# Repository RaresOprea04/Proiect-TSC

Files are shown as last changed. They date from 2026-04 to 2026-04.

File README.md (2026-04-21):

# InkTime - Open Source Smartwatch ⌚

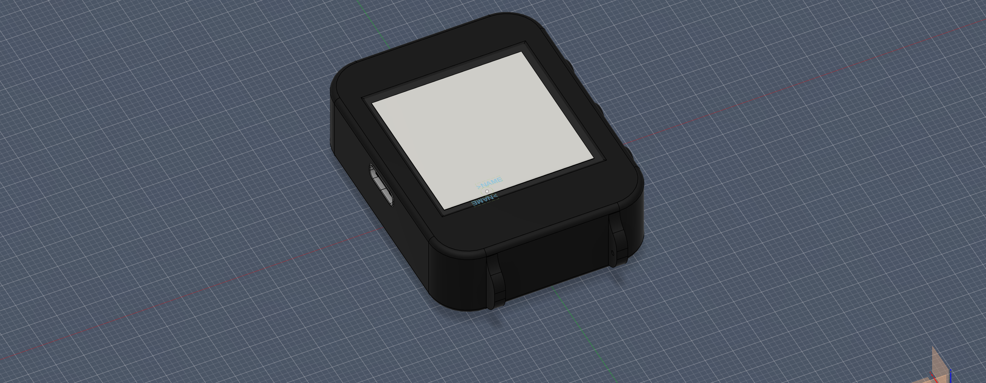
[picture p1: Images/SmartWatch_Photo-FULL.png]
InkTime Smartwatch


InkTime este un start-up care își propune să creeze un smartwatch accesibil și complet open-source. Acest repository conține fișierele FINALE, inclusiv design-ul hardware (schematic + PCB 2D/3D în Fusion 360), fișierele de fabricație și documentația aferentă, cât și ceas-ul în forma sa finală, asamblat.

## 1. Diagrama Bloc a Sistemului

Diagrama de mai jos ilustrează arhitectura hardware a ceasului InkTime, având în centru procesorul nRF52840, înconjurat de modulele de power management, senzori și interfața cu utilizatorul.

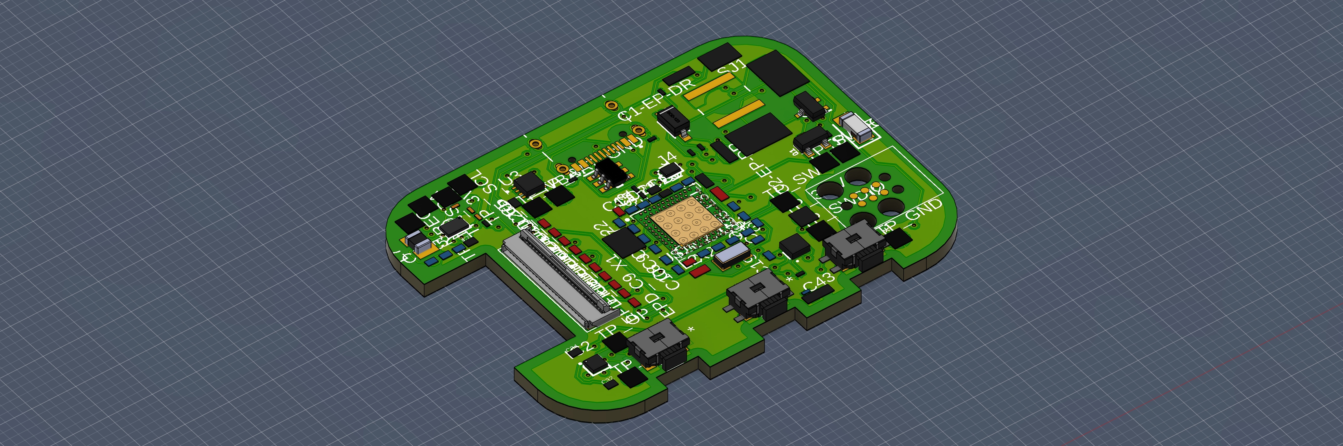
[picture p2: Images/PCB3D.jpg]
Diagrama Bloc
 

```mermaid
flowchart LR
    %% Stiluri
    classDef power fill:#f9d0c4,stroke:#333,stroke-width:2px;
    classDef mcu fill:#d4e6f1,stroke:#333,stroke-width:2px;
    classDef peri fill:#d5f5e3,stroke:#333,stroke-width:2px;

    %% Power Block
    subgraph Power Management
        USB[Conector USB-C]:::power -->|VBUS 5V| BQ[BQ25180\nCharger Li-Po]:::power
        BAT[(Baterie Li-Po)]:::power <-->|VBAT| BQ
        BQ -->|VSYS| REG[RT6160\nRegulator 3.3V]:::power
    end

    %% MCU Block
    MCU{nRF52840 SoC\nMCU + Antenă BLE}:::mcu

    %% Peripherals
    subgraph Senzori & UI
        ACC[BMA421\nAccelerometru]:::peri
        BTN[Butoane Tactile]:::peri
    end

    subgraph Output
        EPD[Ecran E-Paper]:::peri
    end

    Debug[Interfață SWD\nProgramare]:::peri

    %% Power Connections (Linii groase)
    REG == 3.3V === MCU
    REG == 3.3V === ACC
    REG == 3.3V === EPD

    %% Data Connections (Linii normale)
    MCU <-->|I2C| ACC
    MCU -->|SPI| EPD
    BTN -->|GPIO| MCU
    MCU <-->|SWDIO / SWCLK| Debug
```

## 2. Bill of Materials (BOM)

Toate componentele pasive (rezistențe, condensatoare) sunt în format SMD 0201 sau 0402, conform specificațiilor proiectului. Mai jos sunt componentele integrate principale (IC-urile):

| Componentă / Modul | Rol | JLCPCB Part Link | Datasheet |
| :--- | :--- | :--- | :--- |
| **nRF52840-QIAA** | MCU principal (Bluetooth LE) | [Caută JLC](https://jlcpcb.com/parts) | [Datasheet nRF52840](https://infocenter.nordicsemi.com/pdf/nRF52840_PS_v1.1.pdf) |
| **BQ25180YBGR** | PMIC / LiPo Battery Charger | [Caută JLC](https://jlcpcb.com/parts) | [Datasheet BQ25180](https://www.ti.com/lit/ds/symlink/bq25180.pdf) |
| **RT6160AWSC** | DC/DC Buck-Boost Converter (3.3V) | [Caută JLC](https://jlcpcb.com/parts) | [Datasheet RT6160](https://www.richtek.com/assets/product_file/RT6160A/DS6160A-01.pdf) |
| **MAX17048G+T10** | Fuel Gauge (Monitorizare Baterie) | [Caută JLC](https://jlcpcb.com/parts) | [Datasheet MAX17048](https://datasheets.maximintegrated.com/en/ds/MAX17048-MAX17049.pdf) |
| **BMA421** | Senzor IMU (Accelerometru) | [Caută JLC](https://jlcpcb.com/parts) | [Datasheet BMA421](https://www.bosch-sensortec.com/media/boschsensortec/downloads/datasheets/bst-bma421-fl000.pdf) |
| **DRV2605YZFR** | Haptic Motor Driver | [Caută JLC](https://jlcpcb.com/parts) | [Datasheet DRV2605](https://www.ti.com/lit/ds/symlink/drv2605.pdf) |
| **E-Paper Display** | Conector Display FPC 24-pin | - | - |

---

## 3. Funcționalitate Hardware și Arhitectură

Sistemul este construit în jurul microcontroller-ului **Nordic nRF52840**, ales pentru eficiența energetică ridicată și capabilitățile native Bluetooth Low Energy (BLE). 

### Alimentare (Power Management)
* **Încărcare:** Sistemul folosește un încărcător liniar **BQ25180** compatibil cu baterii LiPo, alimentat prin mufa USB-C (5V). 
* **Regulare:** Deoarece bateria variază între 3.0V și 4.2V, folosim un convertor DC/DC Buck-Boost **RT6160** pentru a menține o tensiune stabilă de 3.3V necesară componentelor logice și display-ului.
* **Monitorizare:** Modulul **MAX17048** comunică prin I2C pentru a oferi SoC-ului informații exacte despre procentajul bateriei (State of Charge).

### Senzori și Interacțiune
* **Membru senzorial:** Un IMU **BMA421** comunică prin I2C cu microcontroller-ul. Folosește pini de interupt pentru a trezi procesorul (Wake-on-Motion), economisind astfel energie (ex: se aprinde display-ul doar când ridici mâna).
* **Display E-Paper:** Este controlat printr-o magistrală SPI (MISO, MOSI, SCK, CS) la care se adaugă semnalele de control specifice ecranelor cu cerneală electronică (BUSY, DC, RESET). Avantajul suprem este că ecranul reține imaginea fără a consuma energie (0mA consum static).
* **Feedback Haptic:** Un driver dedicat **DRV2605** este conectat pe magistrala I2C și controlează un motor de vibrații (shaker) pentru notificări.
* **Input Utilizator:** 3 butoane fizice cu rezistențe de pull-up hardware/software pentru navigarea în meniu.

### Estimări de consum energetic
* **Sleep Mode (System OFF):** ~1.5uA (nRF52840) + curenții de stand-by ai senzorilor = **< 5uA total**.
* **Display Refresh:** ~8mA timp de 1-2 secunde (doar la actualizarea orei).
* **BLE Tx/Rx Active:** ~5.3mA pe vârfuri scurte (câteva milisecunde).
Sistemul este extrem de eficient, asigurând o durată de viață a bateriei de câteva săptămâni, în funcție de frecvența refresh-urilor e-paper.

---

## 4. Maparea Pinilor nRF52840 (Pinout)

| Pin nRF52840 | Nume Semnal | Destinație | Rol / Explicație |
| :--- | :--- | :--- | :--- |
| `P0.06` | I2C_SDA | BMA421, BQ25180, MAX17048, DRV2605 | Linia de date pentru magistrala I2C comună. |
| `P0.07` | I2C_SCL | BMA421, BQ25180, MAX17048, DRV2605 | Linia de clock pentru magistrala I2C comună. |
| `P0.03` | SPI_MOSI | E-Paper Connector | Trimite comenzi și date de imagine către display. |
| `P0.02` | SPI_SCK | E-Paper Connector | Semnalul de clock pentru interfața SPI a display-ului. |
| `P0.05` | EPD_CS | E-Paper Connector | Chip Select (active low) pentru display-ul E-paper. |
| `P0.15` | EPD_DC | E-Paper Connector | Data/Command - indică dacă payload-ul trimis prin SPI este o comandă sau date de pixel. |
| `P0.17` | EPD_BUSY | E-Paper Connector | Citește starea de busy a display-ului pentru a ști când s-a terminat refresh-ul. |
| `P0.16` | EPD_RST | E-Paper Connector | Pinul de hardware reset pentru ecranul E-paper. |
| `P0.08` | IMU_INT1 | BMA421 | Wake-up interrupt (ex: trezirea sistemului la ridicarea mâinii). |
| `P1.04` | SW_UP | Buton Sus | Input navigație (activ low, folosind pull-up intern). |
| `P1.05` | SW_ENT | Buton Enter | Input navigație (activ low, folosind pull-up intern). |
| `P1.06` | SW_DN | Buton Jos | Input navigație (activ low, folosind pull-up intern). |

---

## 5. Design Log & Constrângeri pentru Review

### Imagini PCB și Asamblare 3D
*Aici puteți vedea design-ul plăcii de circuit și integrarea acesteia în carcasa printată.*

**Vedere PCB (Top & Bottom):**
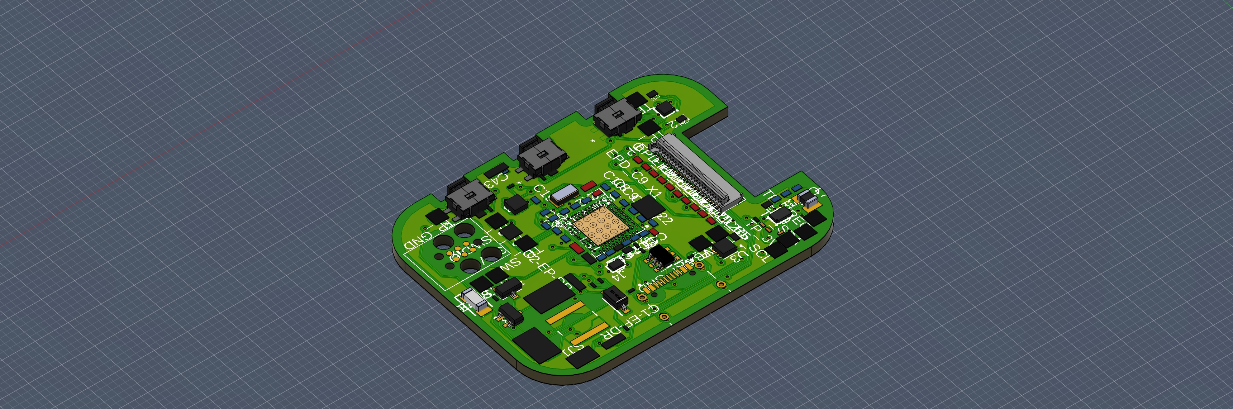
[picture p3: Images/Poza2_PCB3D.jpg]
PCB View 1

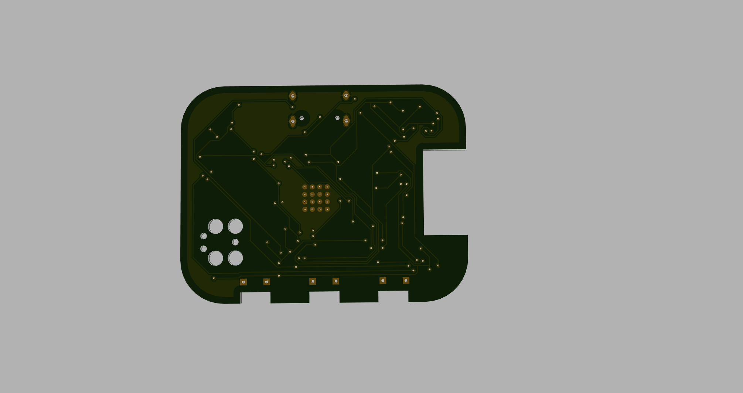
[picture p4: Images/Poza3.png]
PCB View 2


**Integrare în Carcasă (Asamblare internă):**
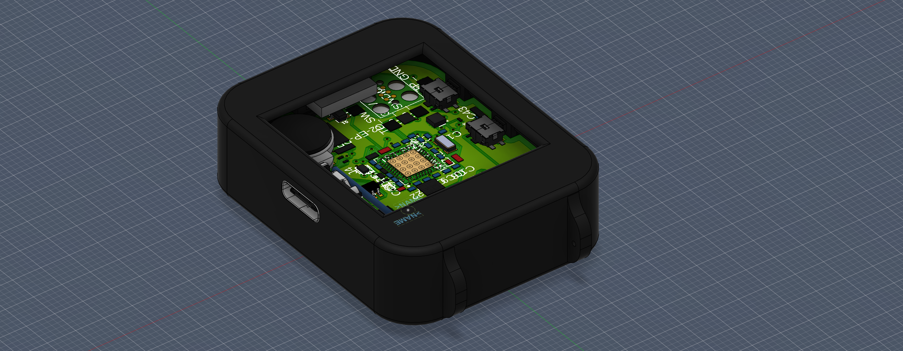
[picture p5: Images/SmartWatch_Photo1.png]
Asamblare 1

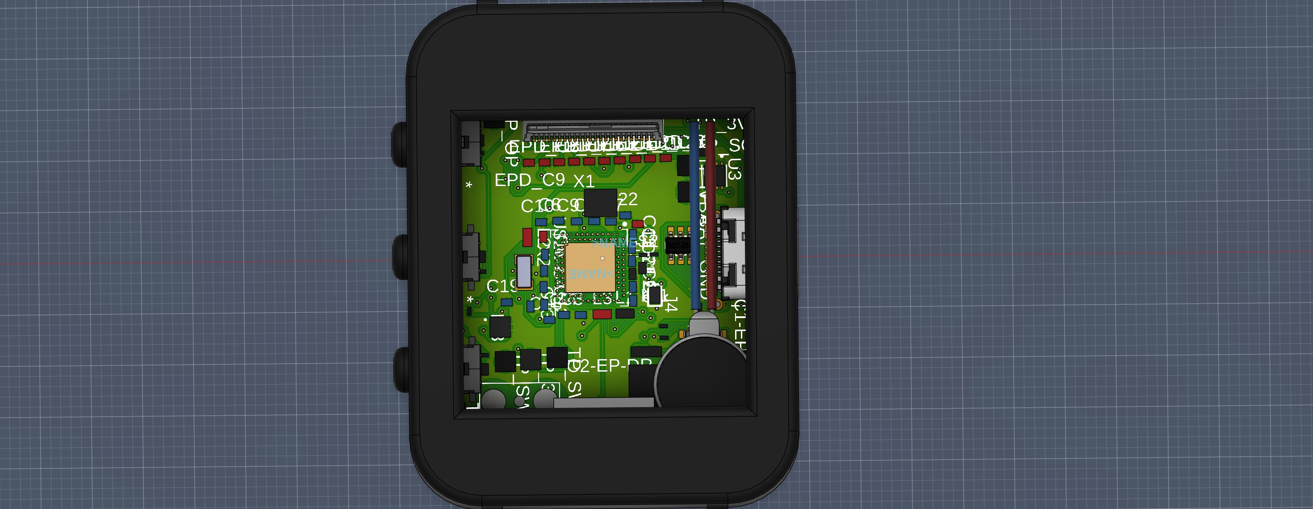
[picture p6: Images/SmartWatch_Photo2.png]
Asamblare 2

Asamblare 3

### Jurnal de decizii (Design Log)
În timpul procesului de proiectare am respectat următoarele constrângeri și decizii de good-practice:
1. **Plane de Masă:** S-au implementat poligoane de GND atât pe layer-ul TOP cât și pe BOTTOM. S-a realizat Via Stitching abundent pentru a asigura un plan de referință solid, în special în apropierea modulului radio și a convertoarelor DC/DC.
2. **Zona Antenei:** Am respectat cu strictețe zona de clearance pentru antena integrată. S-a folosit un "Polygon Cutout" pe ambele straturi pentru a decupa cuprul complet de sub antenă, evitând astfel detunarea (detuning) acesteia și degradarea semnalului RF.
3. **Rutarea curentului:** Traseele de putere (VBUS, 3V3, VBAT) au fost rutate la o grosime optimizată de 0.3mm (unde spațiul a permis) pentru a minimiza căderea de tensiune, iar condensatoarele de decuplare (100nF) au fost amplasate strict, cât mai aproape de pinii de VDD ai integratelor.
4. **Acceptare Erori DRC:** Erorile de clearance și dimension rezultate din depășirea marginii plăcii de către componentele mecanice (mufa USB-C și butoanele fizice) au fost acceptate asumat, deoarece amplasarea lor este impusă de cotele carcasei exterioare.

---

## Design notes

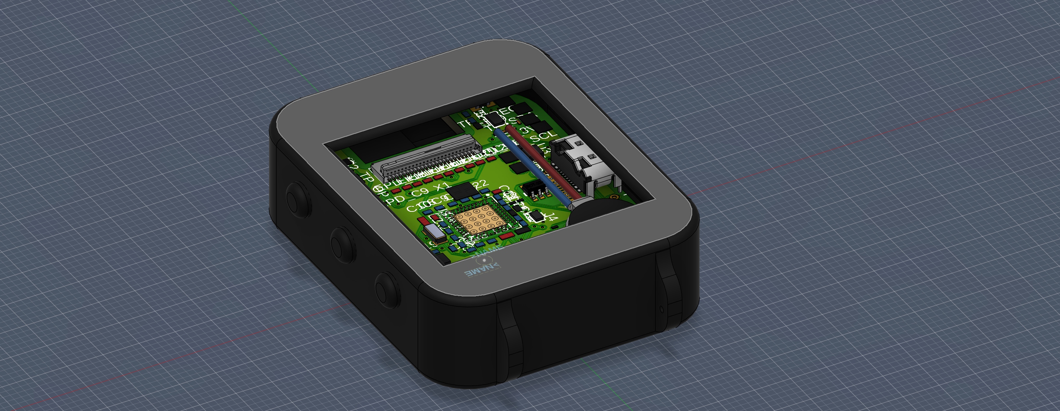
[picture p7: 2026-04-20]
Images/SmartWatch_Photo3.png

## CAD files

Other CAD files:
Mechanical/SmartWatch Final.f3z

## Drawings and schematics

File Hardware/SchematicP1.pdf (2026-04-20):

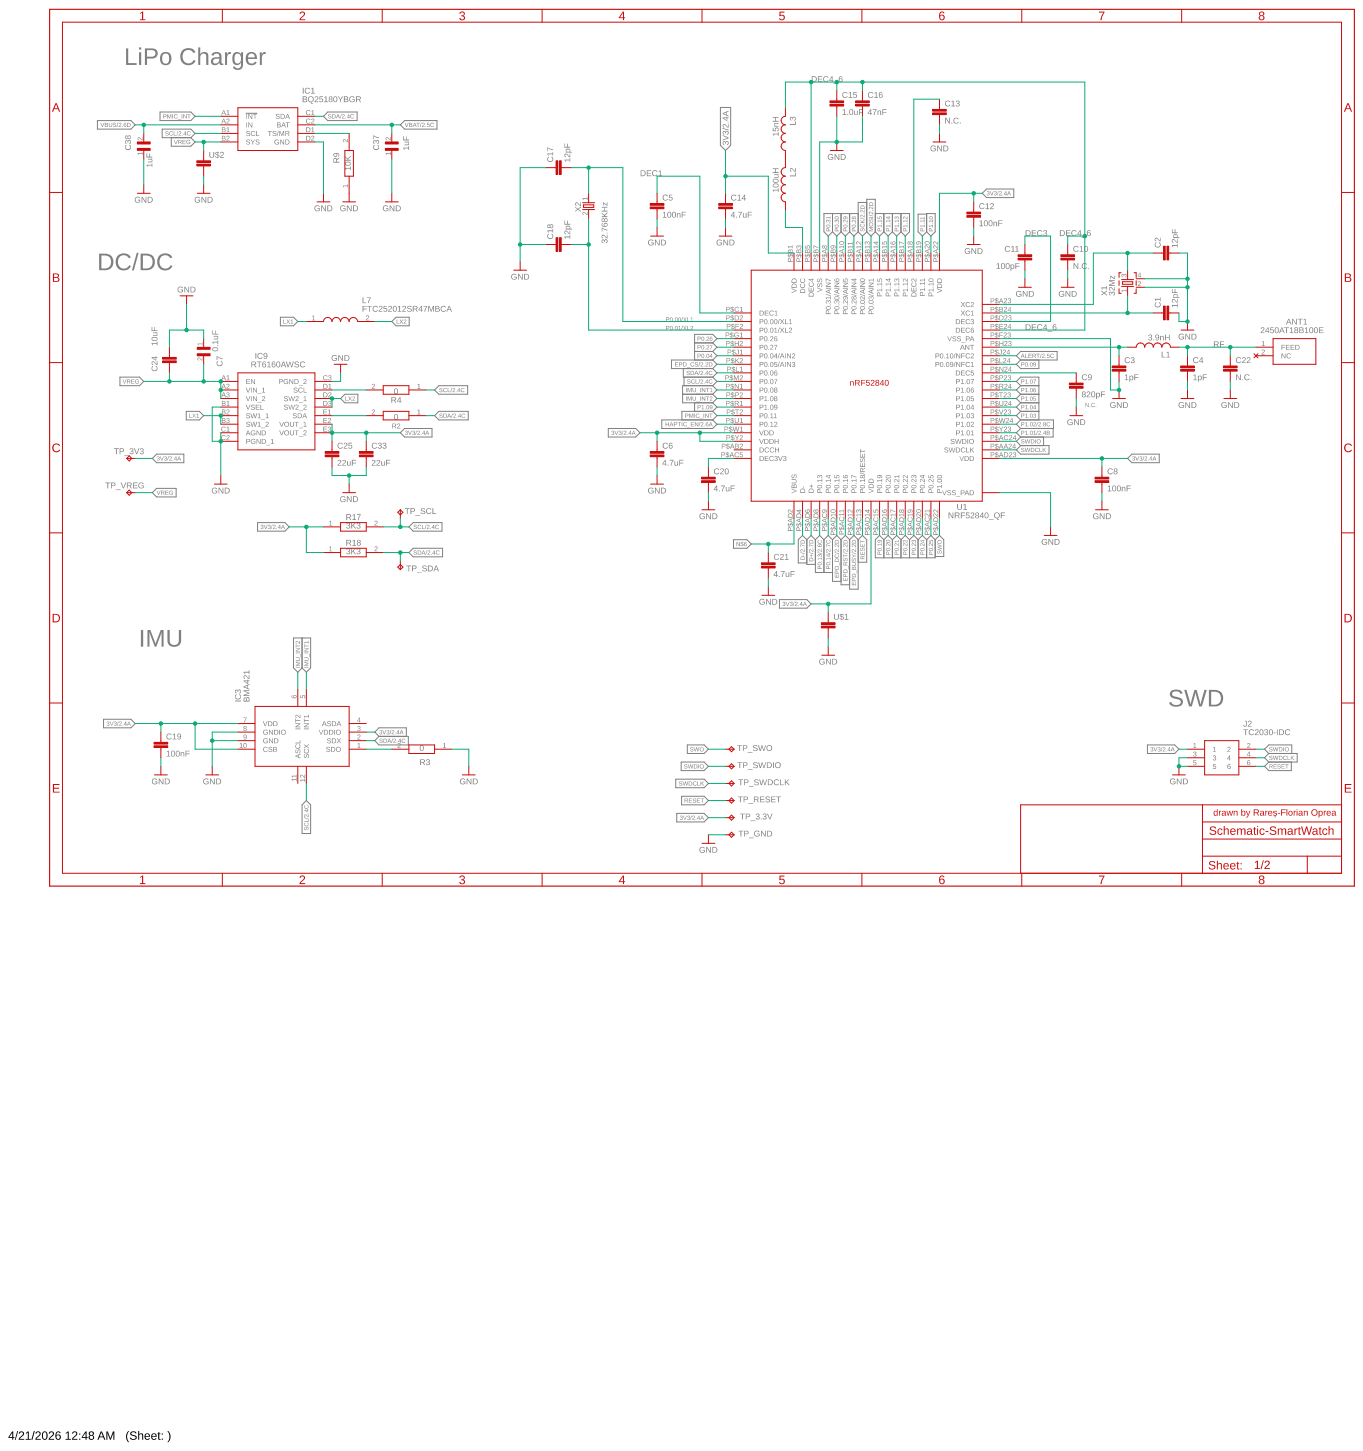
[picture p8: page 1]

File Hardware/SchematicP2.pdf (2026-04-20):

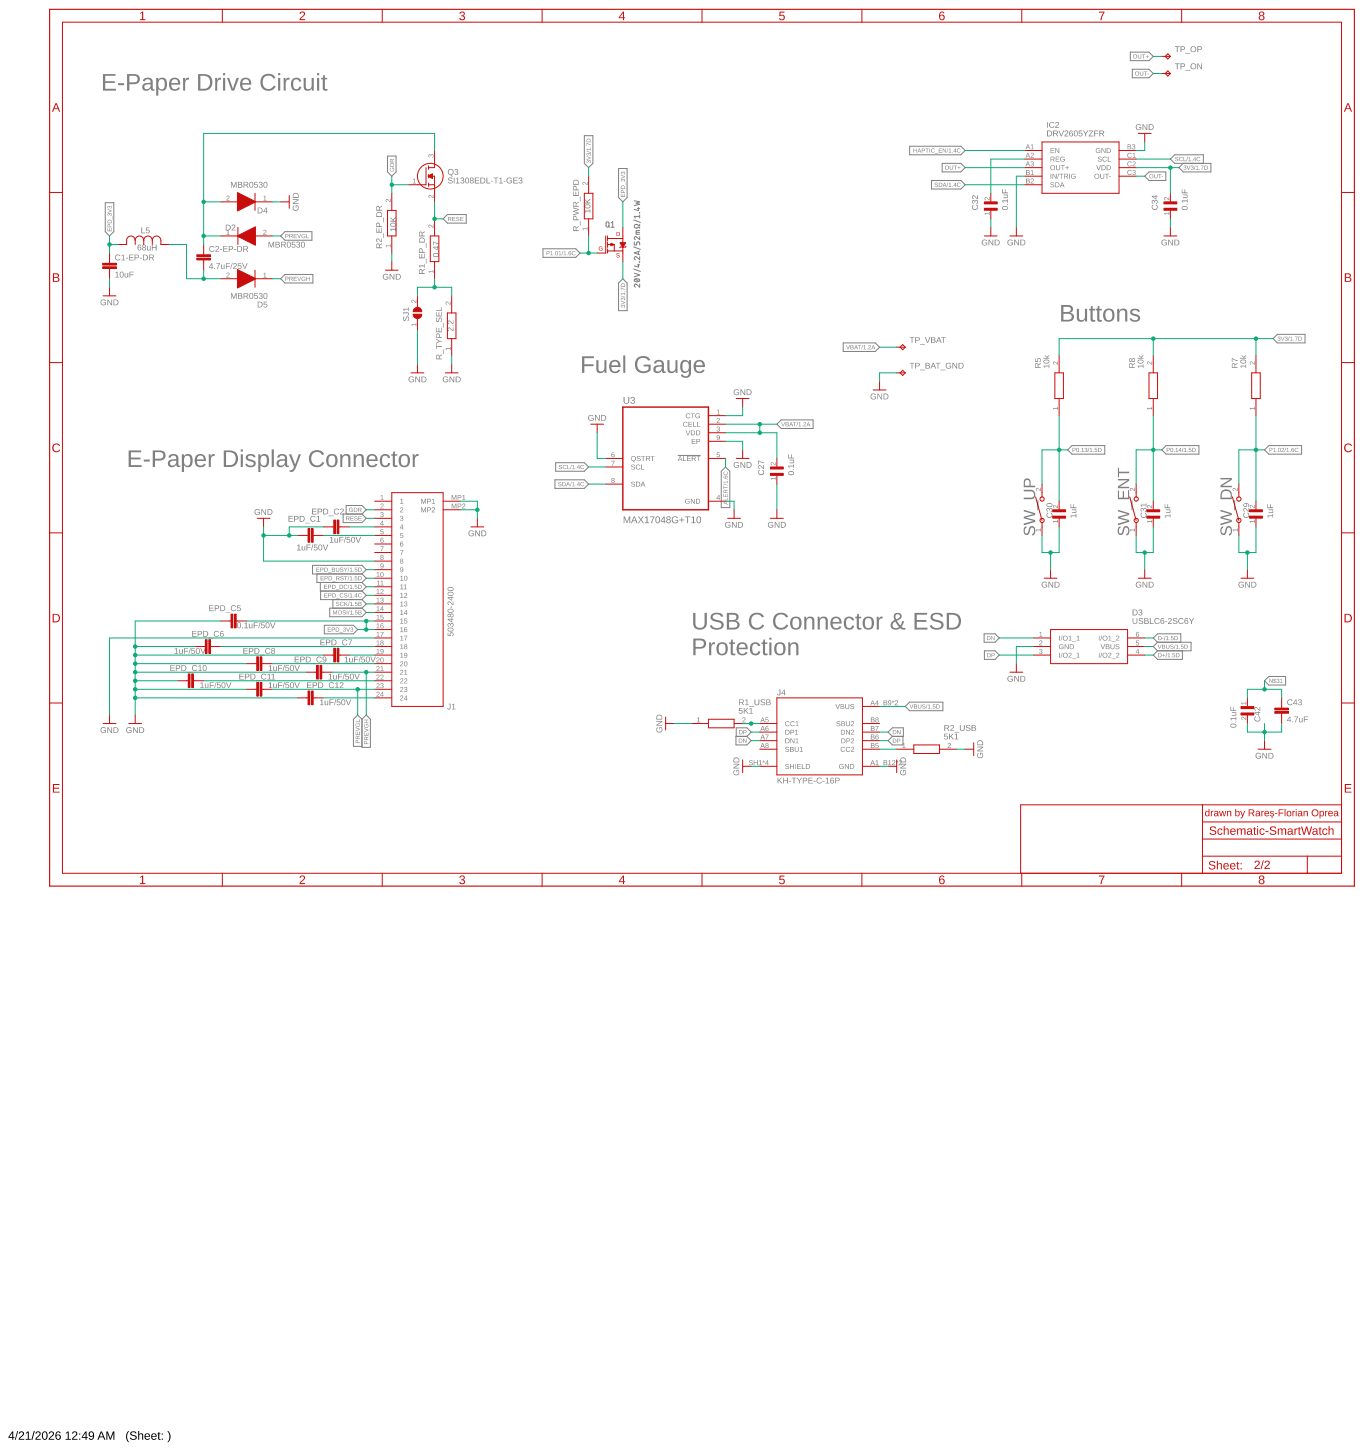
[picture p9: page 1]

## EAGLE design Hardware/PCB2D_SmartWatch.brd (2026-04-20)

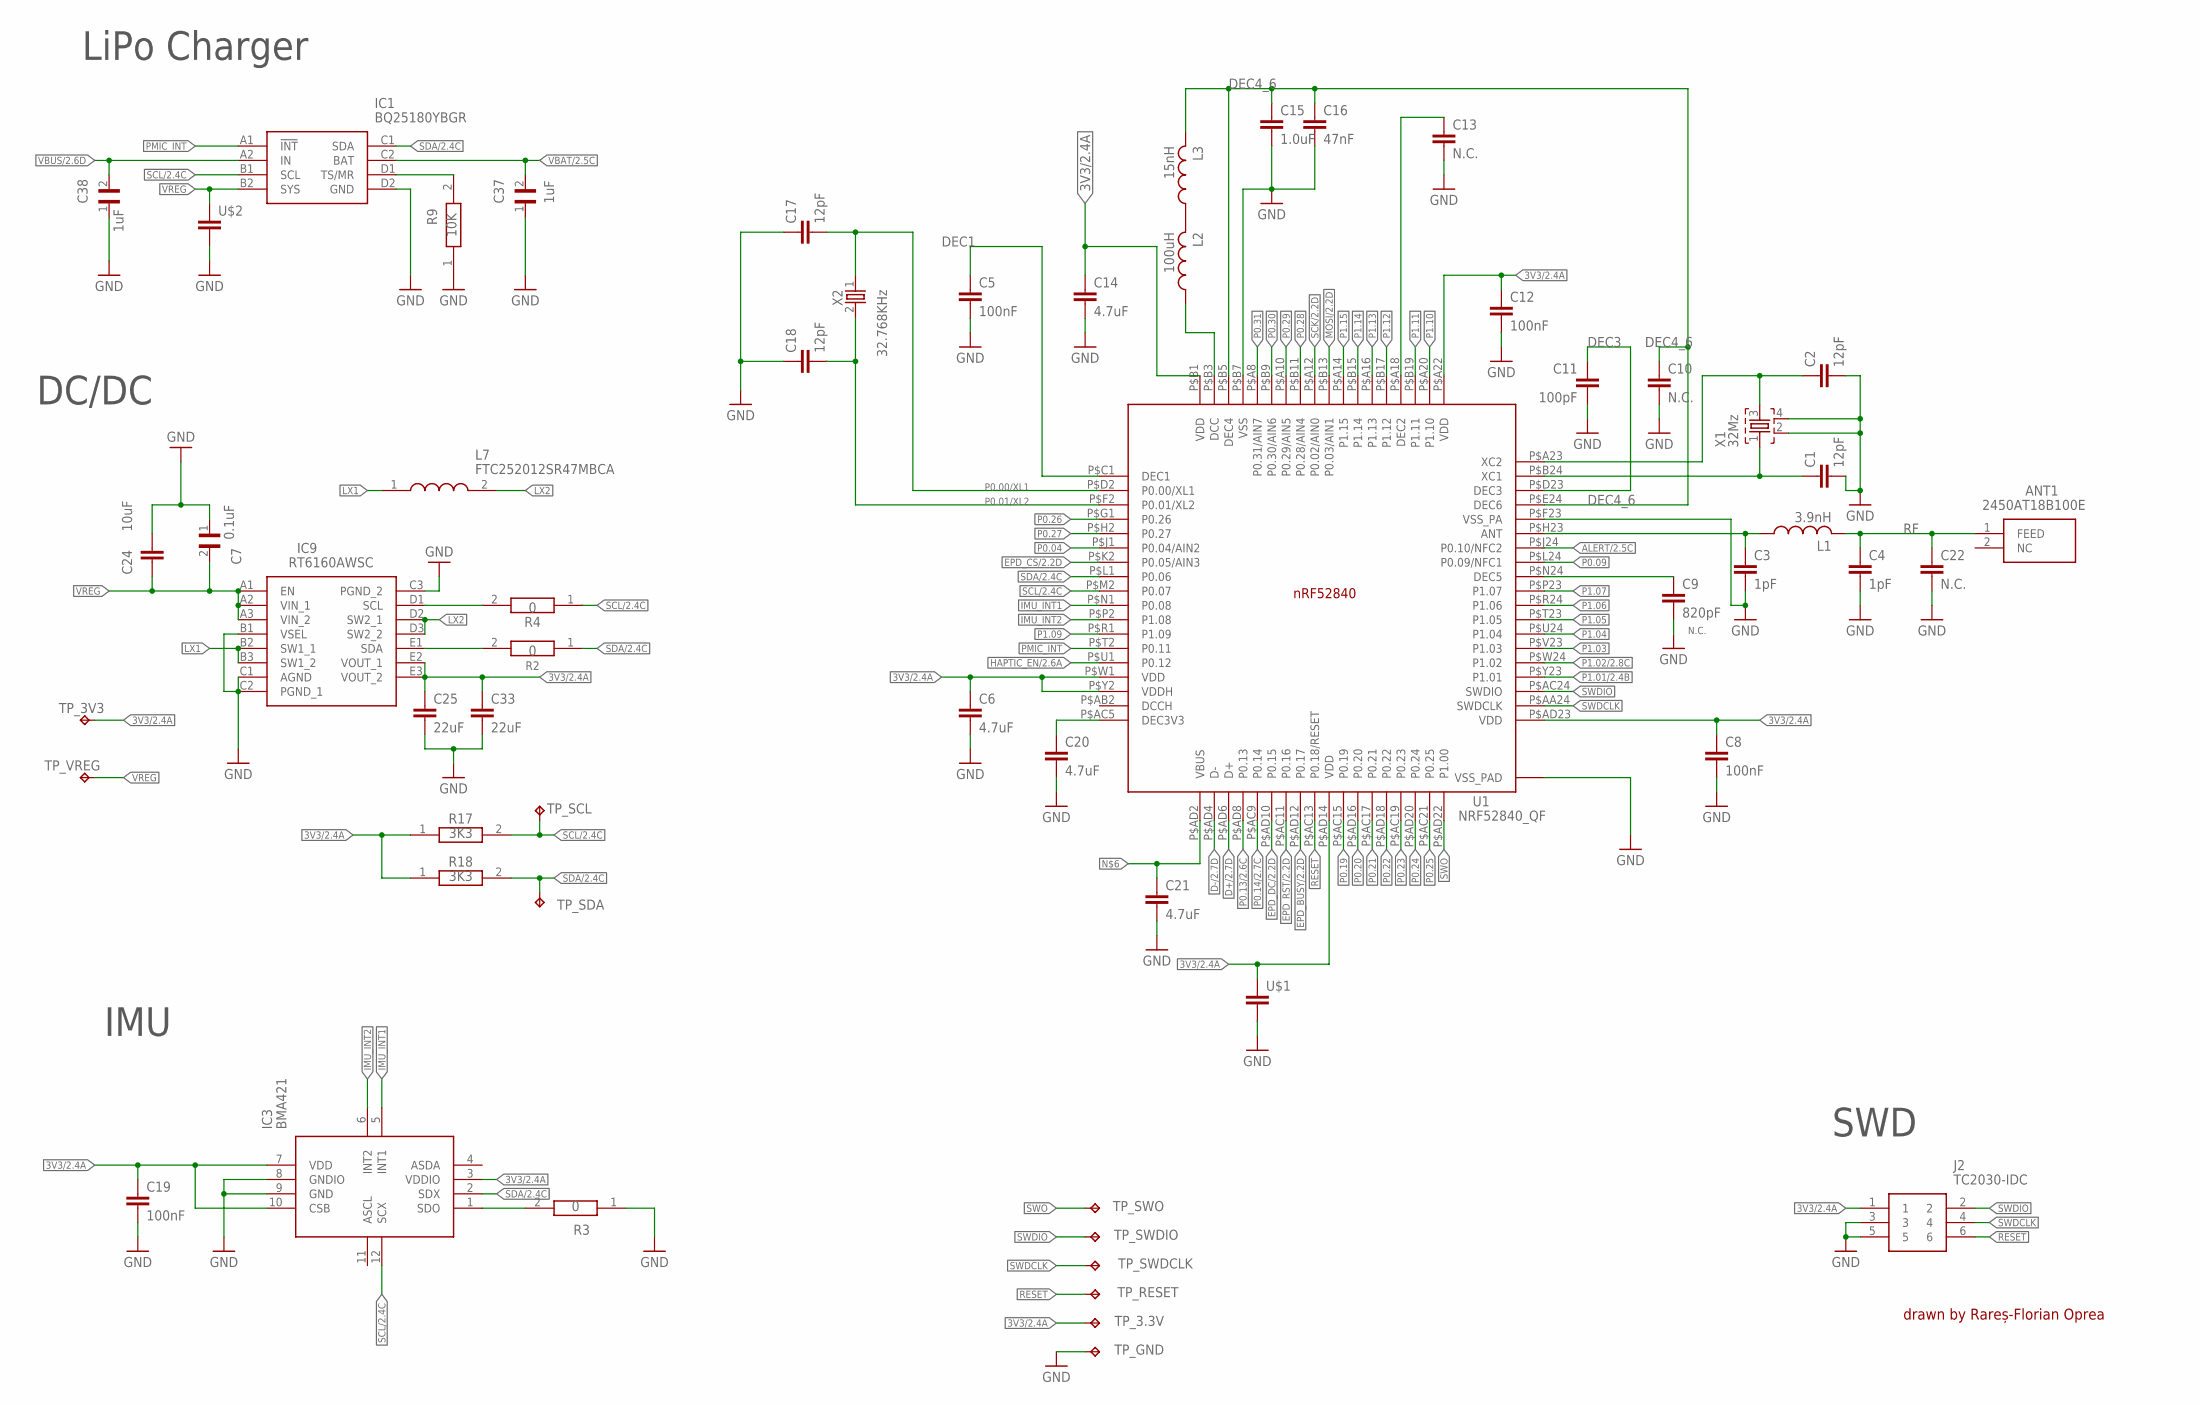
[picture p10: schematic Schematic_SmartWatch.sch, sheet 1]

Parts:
ANT1: 2450AT18B100E; 2450AT18B100E_ANTC3216X140N
C1, C2, C17, C18: 12pF; NORDIC_NRF_3_RESC0201_L
C3, C4: 1pF; NORDIC_NRF_3_RESC0201_L
C5, C8, C12, C19: 100nF; NORDIC_NRF_3_RESC0201_L
C6, C14, C20, C21: 4.7uF; NORDIC_NRF_3_RESC0201_L
C7: 0.1uF; GRM011R60J152KE01L_2_CAPC0201X13N
C9: 820pF; NORDIC_NRF_3_RESC0201_L
C10, C13, C22: N.C.; NORDIC_NRF_3_RESC0201_L
C11: 100pF; NORDIC_NRF_3_RESC0201_L
C15: 1.0uF; NORDIC_NRF_3_RESC0201_L
C16: 47nF; NORDIC_NRF_3_RESC0201_L
C24: 10uF; NORDIC_NRF_3_RESC0201_L
C25, C33: 22uF; NORDIC_NRF_3_RESC0201_L
C37: 1uF; GRM011R60J152KE01L_1_0201
C38: 1uF; GRM011R60J152KE01L_2_CAPC0201X13N
IC1: BQ25180YBGR; BQ25180YBGR_BGA8C40P2X4_100X155X50
IC3: BMA421; BMA423_BMA423
IC9: RT6160AWSC; RT6160AWSC_BGA15C40P3X5_140X230X60
J2: TC2030-IDC; TC2030-IDC_TC2030IDC
L1: 3.9nH; NORDIC_NRF_2_RESC0402_L
L2: 100uH; NORDIC_NRF_2_RESC0402_L
L3: 15nH; NORDIC_NRF_2_RESC0402_L
L7: FTC252012SR47MBCA; MLP2016SR47MT0S1_INDC2016X100N
R2, R4: 0; CPF0201D7K68C1_0201
R3: 0; ERA-1AEB3401C_0201
R9: 10K; ERA-1AEB3401C_0201
R17, R18: 3K3; CPF0201D7K68C1_0201
TP_3.3V, TP_3V3: HECTOR_WATCH_1_TPTP20R; HECTOR_WATCH_1_TP20R
TP_GND: HECTOR_WATCH_1_TPTP20R; HECTOR_WATCH_1_TP20R
TP_RESET: HECTOR_WATCH_1_TPTP20R; HECTOR_WATCH_1_TP20R
TP_SCL: HECTOR_WATCH_1_TPTP20R; HECTOR_WATCH_1_TP20R
TP_SDA: HECTOR_WATCH_1_TPTP20R; HECTOR_WATCH_1_TP20R
TP_SWDCLK: HECTOR_WATCH_1_TPTP20R; HECTOR_WATCH_1_TP20R
TP_SWDIO: HECTOR_WATCH_1_TPTP20R; HECTOR_WATCH_1_TP20R
TP_SWO: HECTOR_WATCH_1_TPTP20R; HECTOR_WATCH_1_TP20R
TP_VREG: HECTOR_WATCH_1_TPTP20R; HECTOR_WATCH_1_TP20R
U1: NRF52840_QF; NORDIC_NRF_4_AQFN50P700X700X85_HS-74N
U$1, U$2: NORDIC_NRF_3_CAPACITOR_0201_L; NORDIC_NRF_3_RESC0201_L
X1: 32Mz; NORDIC_NRF_BT-XTAL_2016_N
X2: 32.768KHz; NORDIC_NRF_1_XTAL_3215_N

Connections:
3V3/2.4A: C6.1, C8.1, C12.1, C14.1, C19.1, C25.1, C33.1, IC3.3 (VDDIO), IC3.7 (VDD), IC3.10 (CSB), IC9.E2 (VOUT_1), IC9.E3 (VOUT_2), J2.1, R17.1, R18.1, TP_3.3V.TP, TP_3V3.TP, U1.P$A22 (VDD), U1.P$AD14 (VDD), U1.P$AD23 (VDD), U1.P$B1 (VDD), U1.P$W1 (VDD), U1.P$Y2 (VDDH), U$1.1
ALERT/2.5C: U1.P$J24 (P0.10/NFC2)
D+/2.7D: U1.P$AD6 (D+)
D-/2.7D: U1.P$AD4 (D-)
DEC1: C5.1, U1.P$C1 (DEC1)
DEC3: C11.1, U1.P$D23 (DEC3)
DEC4_6: C10.1, C15.1, C16.1, L3.2, U1.P$B5 (DEC4), U1.P$E24 (DEC6)
EPD_BUSY/2.2D: U1.P$AD12 (P0.17)
EPD_CS/2.2D: U1.P$K2 (P0.05/AIN3)
EPD_DC/2.2D: U1.P$AD10 (P0.15)
EPD_RST/2.2D: U1.P$AC11 (P0.16)
GND: C1.2, C2.2, C3.2, C4.2, C5.2, C6.2, C7.1, C8.2, C10.2, C11.2, C12.2, C13.2, C14.2, C19.2, C20.2, C21.2, C22.2, C24.1, C37.1, C38.1, IC1.D2 (GND), IC3.8 (GNDIO), IC3.9 (GND), IC9.B1 (VSEL), IC9.C1 (AGND), IC9.C2 (PGND_1), J2.3, J2.5, R3.1, R9.1, TP_GND.TP, U1.P$74 (VSS_PAD), U1.P$75 (VSS_PAD), U1.P$76 (VSS_PAD), U1.P$77 (VSS_PAD), U1.P$78 (VSS_PAD), U1.P$79 (VSS_PAD), U1.P$80 (VSS_PAD), U1.P$81 (VSS_PAD), U1.P$82 (VSS_PAD), U1.P$83 (VSS_PAD), U1.P$84 (VSS_PAD), U1.P$85 (VSS_PAD), U1.P$86 (VSS_PAD), U1.P$87 (VSS_PAD), U1.P$88 (VSS_PAD), U1.P$89 (VSS_PAD), U1.P$90 (VSS_PAD), U1.P$F23 (VSS_PA), U$1.2, U$2.2, X1.2, X1.4; also elsewhere on the board
HAPTIC_EN/2.6A: U1.P$U1 (P0.12)
IMU_INT1: IC3.5 (INT1), U1.P$N1 (P0.08)
IMU_INT2: IC3.6 (INT2), U1.P$P2 (P1.08)
LX1: IC9.B2 (SW1_1), IC9.B3 (SW1_2), L7.1
LX2: IC9.D2 (SW2_1), IC9.D3 (SW2_2), L7.2
MOSI/2.2D: U1.P$B13 (P0.03/AIN1)
unnamed: L2.2, L3.1
unnamed: L2.1, U1.P$B3 (DCC)
unnamed: IC1.D1 (TS/MR), R9.2
unnamed: C15.2, C16.2, U1.P$B7 (VSS)
unnamed: C20.1, U1.P$AC5 (DEC3V3)
unnamed: C21.1, U1.P$AD2 (VBUS)
unnamed: C17.1, C18.1
unnamed: C3.1, L1.1, U1.P$H23 (ANT)
unnamed: C1.1, U1.P$B24 (XC1), X1.1
unnamed: C13.1, U1.P$A18 (DEC2)
unnamed: C9.1, U1.P$N24 (DEC5)
unnamed: C2.1, U1.P$A23 (XC2), X1.3
unnamed: IC3.1 (SDO), R3.2
unnamed: IC9.D1 (SCL), R4.2
unnamed: C25.2, C33.2
unnamed: IC9.E1 (SDA), R2.2
N.C.: C9.2
P0.00/XL1: C17.2, U1.P$D2 (P0.00/XL1), X2.1
P0.01/XL2: C18.2, U1.P$F2 (P0.01/XL2), X2.2
P0.04: U1.P$J1 (P0.04/AIN2)
P0.09: U1.P$L24 (P0.09/NFC1)
P0.13/2.6C: U1.P$AD8 (P0.13)
P0.14/2.7C: U1.P$AC9 (P0.14)
P0.19: U1.P$AC15 (P0.19)
P0.20: U1.P$AD16 (P0.20)
P0.21: U1.P$AC17 (P0.21)
P0.22: U1.P$AD18 (P0.22)
P0.23: U1.P$AC19 (P0.23)
P0.24: U1.P$AD20 (P0.24)
P0.25: U1.P$AC21 (P0.25)
P0.26: U1.P$G1 (P0.26)
P0.27: U1.P$H2 (P0.27)
P0.28: U1.P$B11 (P0.28/AIN4)
P0.29: U1.P$A10 (P0.29/AIN5)
P0.30: U1.P$B9 (P0.30/AIN6)
P0.31: U1.P$A8 (P0.31/AIN7)
P1.01/2.4B: U1.P$Y23 (P1.01)
P1.02/2.8C: U1.P$W24 (P1.02)
P1.03: U1.P$V23 (P1.03)
P1.04: U1.P$U24 (P1.04)
P1.05: U1.P$T23 (P1.05)
P1.06: U1.P$R24 (P1.06)
P1.07: U1.P$P23 (P1.07)
P1.09: U1.P$R1 (P1.09)
P1.10: U1.P$A20 (P1.10)
P1.11: U1.P$B19 (P1.11)
P1.12: U1.P$B17 (P1.12)
P1.13: U1.P$A16 (P1.13)
P1.14: U1.P$B15 (P1.14)
P1.15: U1.P$A14 (P1.15)
PMIC_INT: IC1.A1 (!INT), U1.P$T2 (P0.11)
RESET: J2.6, TP_RESET.TP, U1.P$AC13 (P0.18/RESET)
RF: ANT1.1 (FEED), C4.1, C22.1, L1.2
SCK/2.2D: U1.P$A12 (P0.02/AIN0)
SCL/2.4C: IC1.B1 (SCL), IC3.12 (SCX), R4.1, R17.2, TP_SCL.TP, U1.P$M2 (P0.07)
SDA/2.4C: IC1.C1 (SDA), IC3.2 (SDX), R2.1, R18.2, TP_SDA.TP, U1.P$L1 (P0.06)
SWDCLK: J2.4, TP_SWDCLK.TP, U1.P$AA24 (SWDCLK)
SWDIO: J2.2, TP_SWDIO.TP, U1.P$AC24 (SWDIO)
SWO: TP_SWO.TP, U1.P$AD22 (P1.00)
VBAT/2.5C: C37.2, IC1.C2 (BAT)
VBUS/2.6D: C38.2, IC1.A2 (IN)
VREG: C7.2, C24.2, IC1.B2 (SYS), IC9.A1 (EN), IC9.A2 (VIN_1), IC9.A3 (VIN_2), TP_VREG.TP, U$2.1

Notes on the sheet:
LiPo Charger
IMU
DC/DC
SWD
drawn by Rareș-Florian Oprea

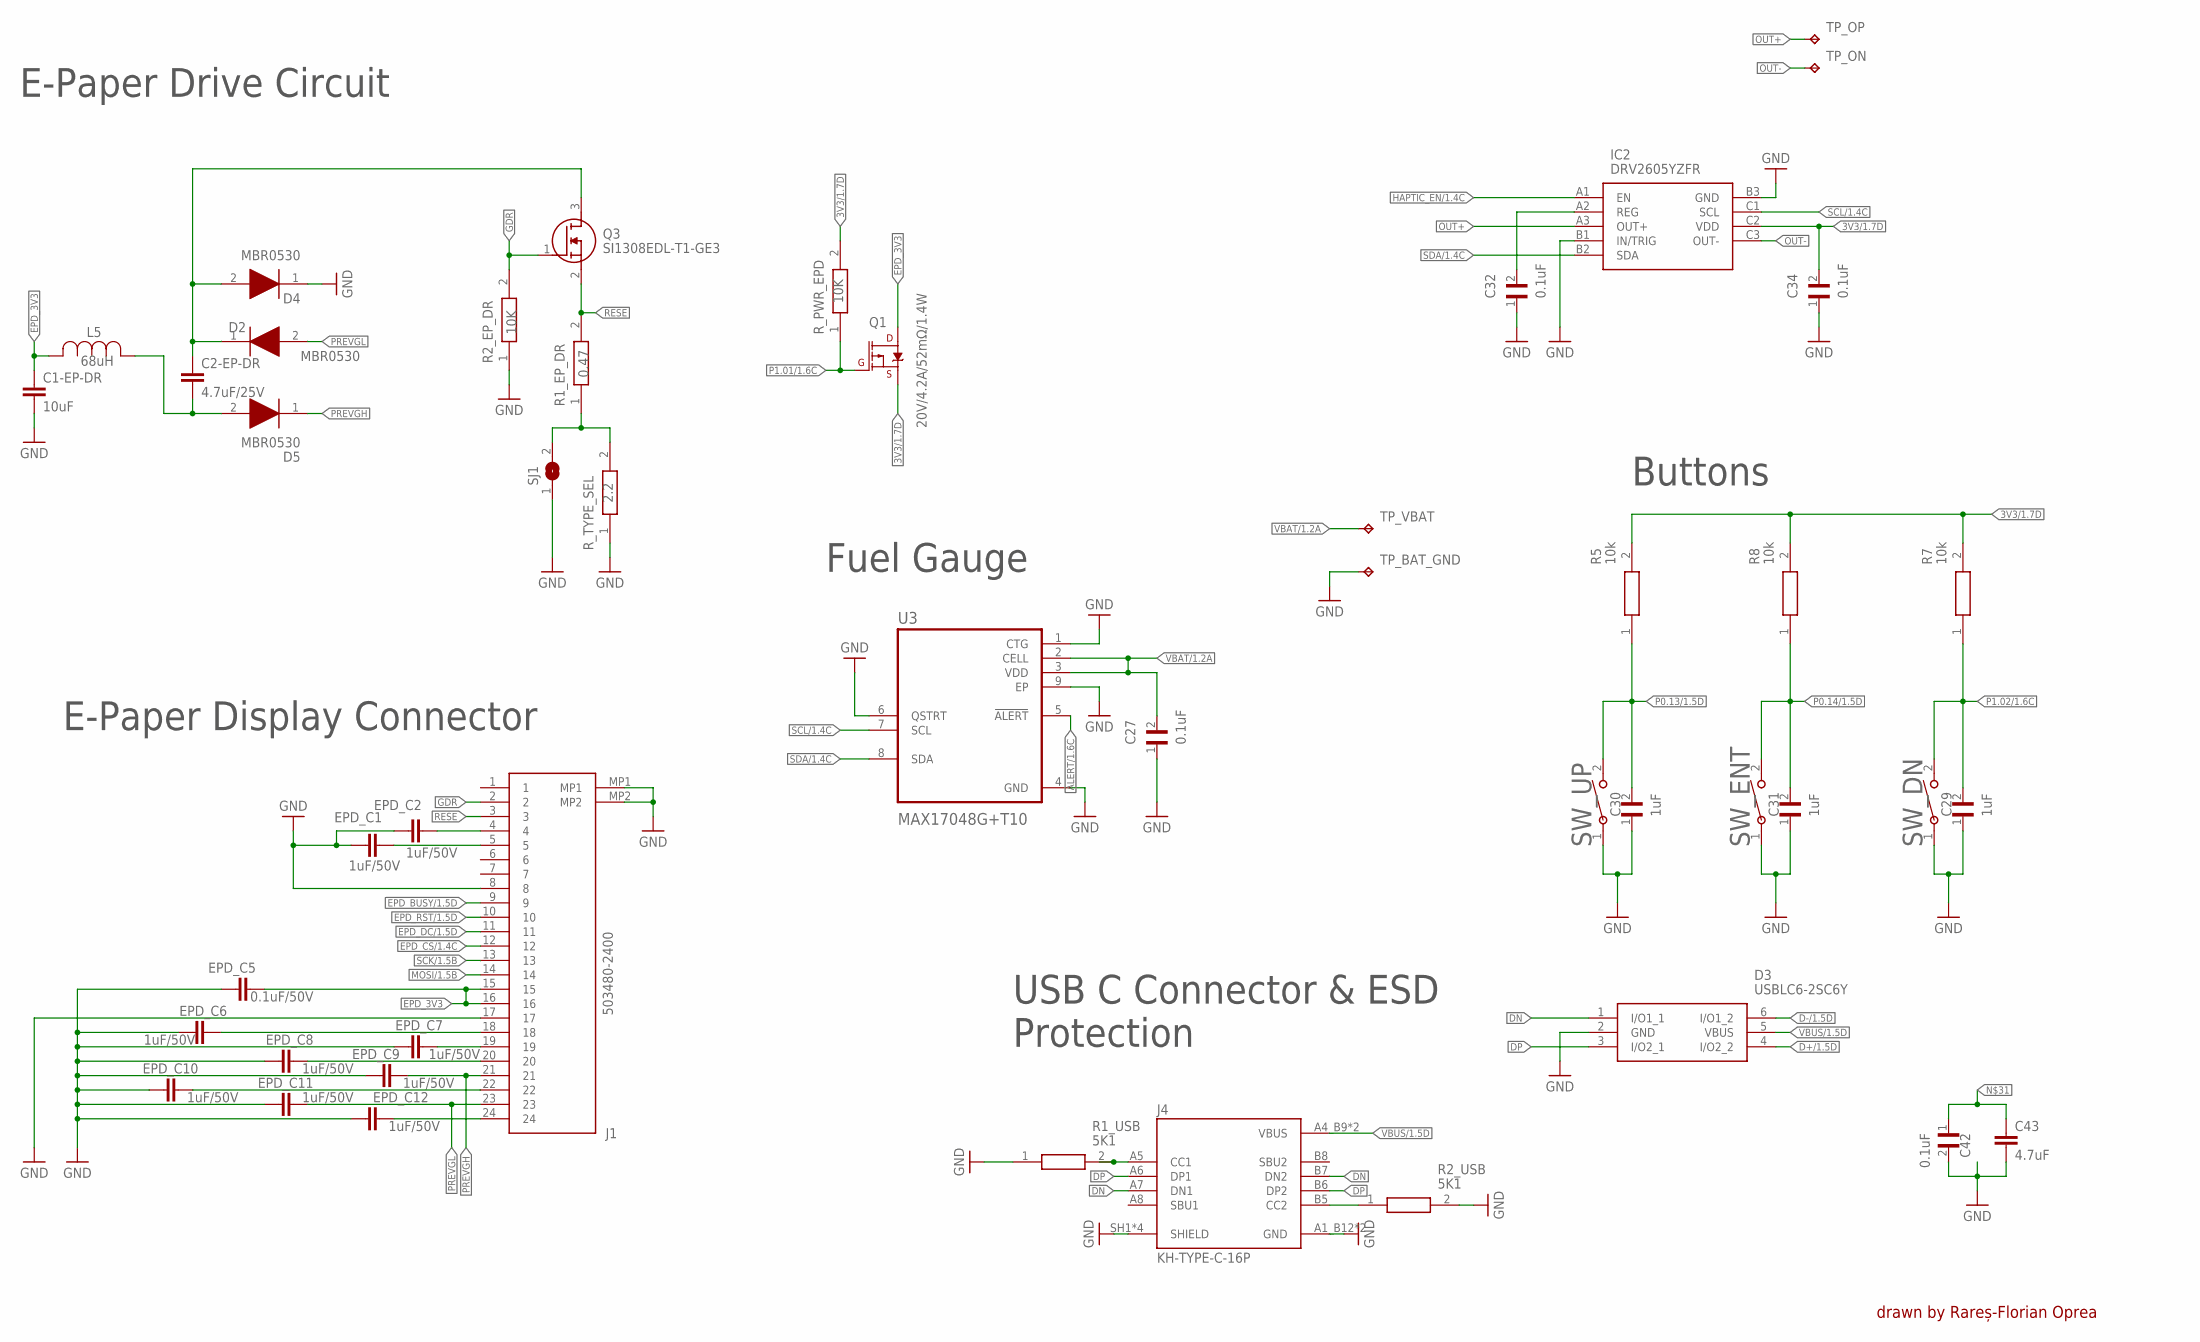
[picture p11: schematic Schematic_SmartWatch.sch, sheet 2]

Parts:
C1-EP-DR: 10uF; ESP32_C6_LIBRARY_1_ESP32_WROVER_EAGLE-LTSPICE_C0402
C2-EP-DR: 4.7uF/25V; ESP32_C6_LIBRARY_1_ESP32_WROVER_EAGLE-LTSPICE_C0402
C27, C32, C34: 0.1uF; GRM011R60J152KE01L_2_CAPC0201X13N
C29, C30, C31: 1uF; GRM011R60J152KE01L_2_CAPC0201X13N
C42: 0.1uF; GRM011R60J152KE01L_1_0201
C43: 4.7uF; ESP32_C6_LIBRARY_1_ESP32_WROVER_EAGLE-LTSPICE_C0402
D2, D4, D5: MBR0530; ESP32_C6_LIBRARY_5_SOD3716X135N
D3: USBLC6-2SC6Y; ESP32_C6_LIBRARY_3_SOT95P280X145-6N
EPD_C1, EPD_C2, EPD_C6, EPD_C7, EPD_C8, EPD_C9, EPD_C10, EPD_C11, EPD_C12: 1uF/50V; NORDIC_NRF_3_RESC0201_L
EPD_C5: 0.1uF/50V; NORDIC_NRF_3_RESC0201_L
IC2: DRV2605YZFR; DRV2605YZFR_BGA9C50P3X3_144X144X62
J1: 503480-2400; 503480-2400_5034802400
J4: KH-TYPE-C-16P; KH-TYPE-C-16P_KINGHELM_KH-TYPE-C-16P
L5: 68uH; ESP32_C6_LIBRARY_2_IND_4828-WE-TPC_WRE
Q1: 20V/4.2A/52mΩ/1.4W; ESP32_C6_LIBRARY_4_ESP32_C6_LIBRARY_4_ESP32_C6_LIBRARY_4_ES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
Q3: SI1308EDL-T1-GE3; ESP32_C6_LIBRARY_6_SOT65P210X110-3N
R1_EP_DR: 0.47; ERA-1AEB3401C_0201
R1_USB, R2_USB: 5K1; ERA-1AEB3401C_0201
R2_EP_DR: 10K; ERA-1AEB3401C_0201
R5, R7, R8: 10k; ERA-1AEB3401C_0201
R_PWR_EPD: 10K; ERA-1AEB3401C_0201
R_TYPE_SEL: 2.2; ERA-1AEB3401C_0201
SJ1: ESP32_C6_LIBRARY_7_JUMPER_SJ
SW_DN: 2025-10-22_07-23-44_LIBRARY_EVP-AKE31ASW_EVP-AKE3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; 2025-10-22_07-23-44_LIBRARY_SW_EVP-AKE31A_PAN
SW_ENT: 2025-10-22_07-23-44_LIBRARY_EVP-AKE31ASW_EVP-AKE3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; 2025-10-22_07-23-44_LIBRARY_SW_EVP-AKE31A_PAN
SW_UP: 2025-10-22_07-23-44_LIBRARY_EVP-AKE31ASW_EVP-AKE3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; 2025-10-22_07-23-44_LIBRARY_SW_EVP-AKE31A_PAN
TP_BAT_GND: HECTOR_WATCH_1_TPTP20R; HECTOR_WATCH_1_TP20R
TP_ON: HECTOR_WATCH_1_TPTP20R; HECTOR_WATCH_1_TP20R
TP_OP: HECTOR_WATCH_1_TPTP20R; HECTOR_WATCH_1_TP20R
TP_VBAT: HECTOR_WATCH_1_TPTP20R; HECTOR_WATCH_1_TP20R
U3: MAX17048G+T10; ESP32_C6_LIBRARY_SON50P200X200X80-9N

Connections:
3V3/1.7D: C34.2, IC2.C2 (VDD), Q1.2 (S), R5.2, R7.2, R8.2, R_PWR_EPD.2
ALERT/1.6C: U3.5 (!ALERT)
D+/1.5D: D3.4 (I/O2_2)
D-/1.5D: D3.6 (I/O1_2)
DN: D3.1 (I/O1_1), J4.A7 (DN1), J4.B7 (DN2)
DP: D3.3 (I/O2_1), J4.A6 (DP1), J4.B6 (DP2)
EPD_3V3: C1-EP-DR.1, EPD_C5.2, J1.15, J1.16, L5.2, Q1.3 (D)
EPD_BUSY/1.5D: J1.9
EPD_CS/1.4C: J1.12
EPD_DC/1.5D: J1.11
EPD_RST/1.5D: J1.10
GDR: J1.2, Q3.1 (G), R2_EP_DR.2
GND: C1-EP-DR.2, C27.1, C29.1, C30.1, C31.1, C32.1, C34.1, C42.2, C43.2, D4.1 (K), EPD_C1.1, EPD_C2.1, EPD_C5.1, EPD_C6.1, EPD_C7.1, EPD_C8.1, EPD_C9.1, EPD_C10.1, EPD_C11.1, EPD_C12.1, IC2.B1 (IN/TRIG), J1.8, J1.17, J1.MP1, J1.MP2, J4.A1_B12 (GND), J4.A12_B1 (GND), J4.SH1 (SHIELD), J4.SH2 (SHIELD), J4.SH3 (SHIELD), J4.SH4 (SHIELD), R1_USB.1, R2_EP_DR.1, R2_USB.2, R_TYPE_SEL.1, SJ1.1, SW_DN.1, SW_ENT.1, SW_UP.1, TP_BAT_GND.TP, U3.1 (CTG), U3.4 (GND), U3.6 (QSTRT), U3.9 (EP); also elsewhere on the board
HAPTIC_EN/1.4C: IC2.A1 (EN)
MOSI/1.5B: J1.14
unnamed: EPD_C2.2, J1.4
unnamed: EPD_C1.2, J1.5
unnamed: EPD_C12.2, J1.24
unnamed: R1_EP_DR.1, R_TYPE_SEL.2, SJ1.2
unnamed: C2-EP-DR.2, D5.2 (A), L5.1
unnamed: EPD_C10.2, J1.22
unnamed: C2-EP-DR.1, D2.1 (K), D4.2 (A), Q3.3 (D)
unnamed: EPD_C7.2, J1.19
unnamed: EPD_C8.2, J1.20
unnamed: EPD_C6.2, J1.18
unnamed: C32.2, IC2.A2 (REG)
unnamed: C42.1, C43.1
unnamed: J4.B5 (CC2), R2_USB.1
unnamed: J4.A5 (CC1), R1_USB.2
OUT+: IC2.A3 (OUT+), TP_OP.TP
OUT-: IC2.C3 (OUT-), TP_ON.TP
P0.13/1.5D: C30.2, R5.1, SW_UP.2
P0.14/1.5D: C31.2, R8.1, SW_ENT.2
P1.01/1.6C: Q1.1 (G), R_PWR_EPD.1
P1.02/1.6C: C29.2, R7.1, SW_DN.2
PREVGH: D5.1 (K), EPD_C9.2, J1.21
PREVGL: D2.2 (A), EPD_C11.2, J1.23
RESE: J1.3, Q3.2 (S), R1_EP_DR.2
SCK/1.5B: J1.13
SCL/1.4C: IC2.C1 (SCL), U3.7 (SCL)
SDA/1.4C: IC2.B2 (SDA), U3.8 (SDA)
VBAT/1.2A: C27.2, TP_VBAT.TP, U3.2 (CELL), U3.3 (VDD)
VBUS/1.5D: D3.5 (VBUS), J4.A4_B9 (VBUS), J4.A9_B4 (VBUS)

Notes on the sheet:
drawn by Rareș-Florian Oprea
E-Paper Display Connector
E-Paper Drive Circuit
Fuel Gauge
Buttons
USB C Connector & ESD Protection

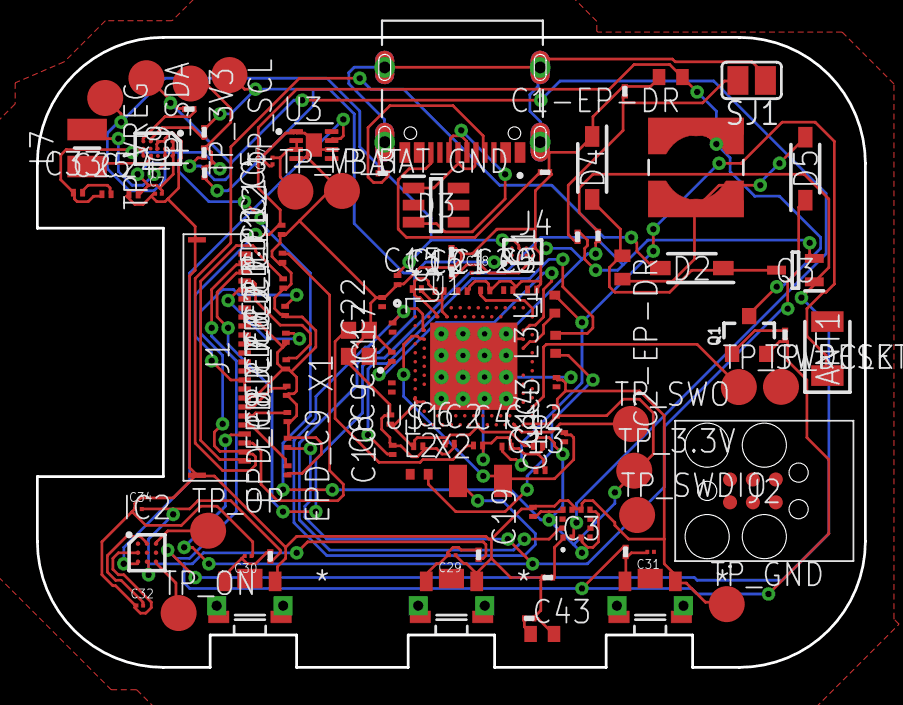
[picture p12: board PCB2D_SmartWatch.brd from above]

Board: 2 copper layers, 46.0 x 35.0 mm, 105 parts (0 on the bottom side), 70 nets.

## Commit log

2026-04-10 Project Almost Done
    [PCB2D-SmartWatch.brd, Schematic-SmartWatch.sch]
2026-04-20 Done Project
    [PCB2D-SmartWatch.brd, PCB2D_SmartWatch.brd, PCB3D-SmartWatch.f3d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]

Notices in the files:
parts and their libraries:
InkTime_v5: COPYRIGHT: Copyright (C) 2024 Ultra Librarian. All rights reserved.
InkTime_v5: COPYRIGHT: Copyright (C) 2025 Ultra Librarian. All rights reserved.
